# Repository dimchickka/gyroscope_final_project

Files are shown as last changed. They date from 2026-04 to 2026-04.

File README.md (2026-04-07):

Gyroscope Data Logger (STM32F103C8T6)
Overview
This project is an autonomous data logging device built around the STM32F103C8T6 (Blue Pill) microcontroller. It reads real-time data from a gyroscope sensor and saves the logs directly onto an SD card. The device is designed for portability, powered by a LiPo battery featuring convenient USB charging.

Photo Gallery
<div align="center">
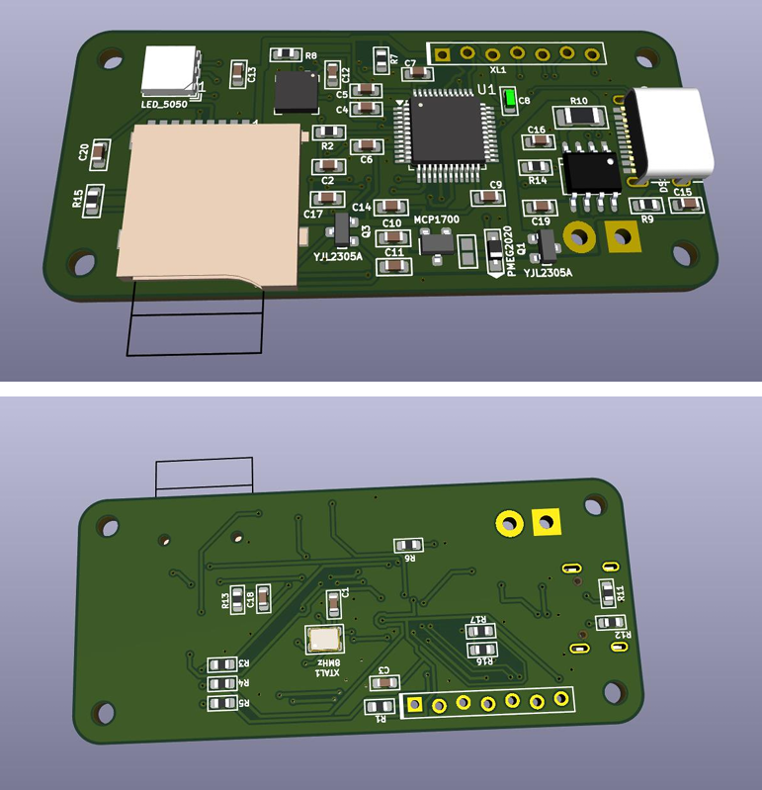
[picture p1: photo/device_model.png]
Model in KiCAD View

</div>

<div align="center">
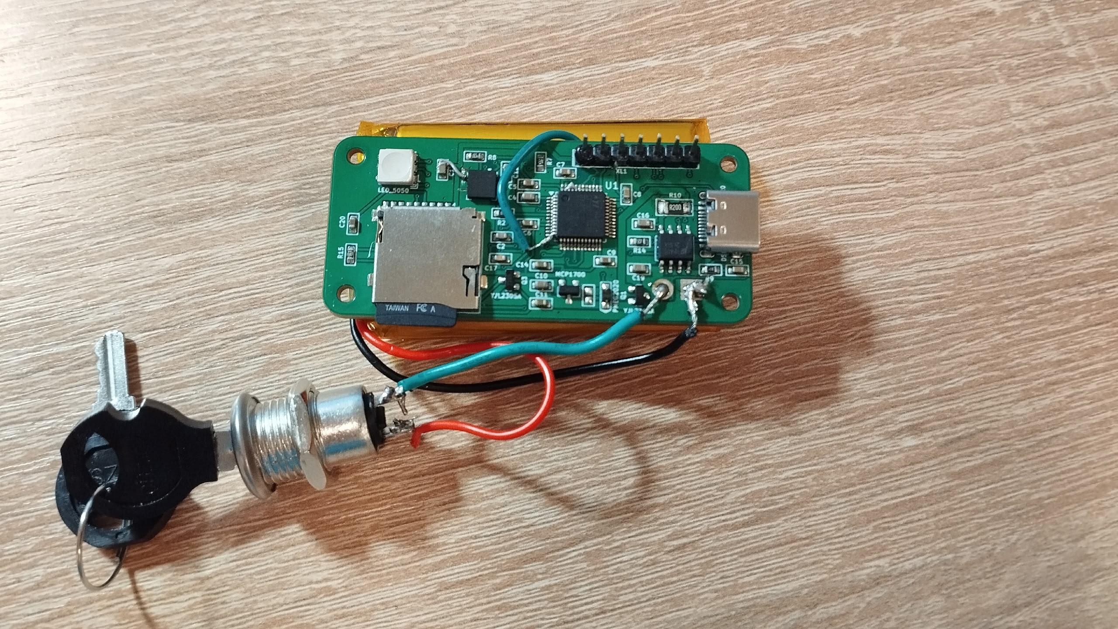
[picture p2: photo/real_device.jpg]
Assembled Device View

<p><em>The fully assembled Gyroscope Data Logger.</em></p>
</div>

🚀 Key Features
Microcontroller: STM32F103C8T6 (Cortex-M3).

Sensor: High-precision Gyroscope (interfaced via I2C).

Data Storage: Reliable data logging to a MicroSD card

Power System: Portable LiPo battery operation with an integrated USB charging circuit.

Communication Interfaces:

SPI: Used for high-speed communication with the SD card module.

I2C: Used for retrieving sensor data from the gyroscope.

UART: Available for debugging purposes.

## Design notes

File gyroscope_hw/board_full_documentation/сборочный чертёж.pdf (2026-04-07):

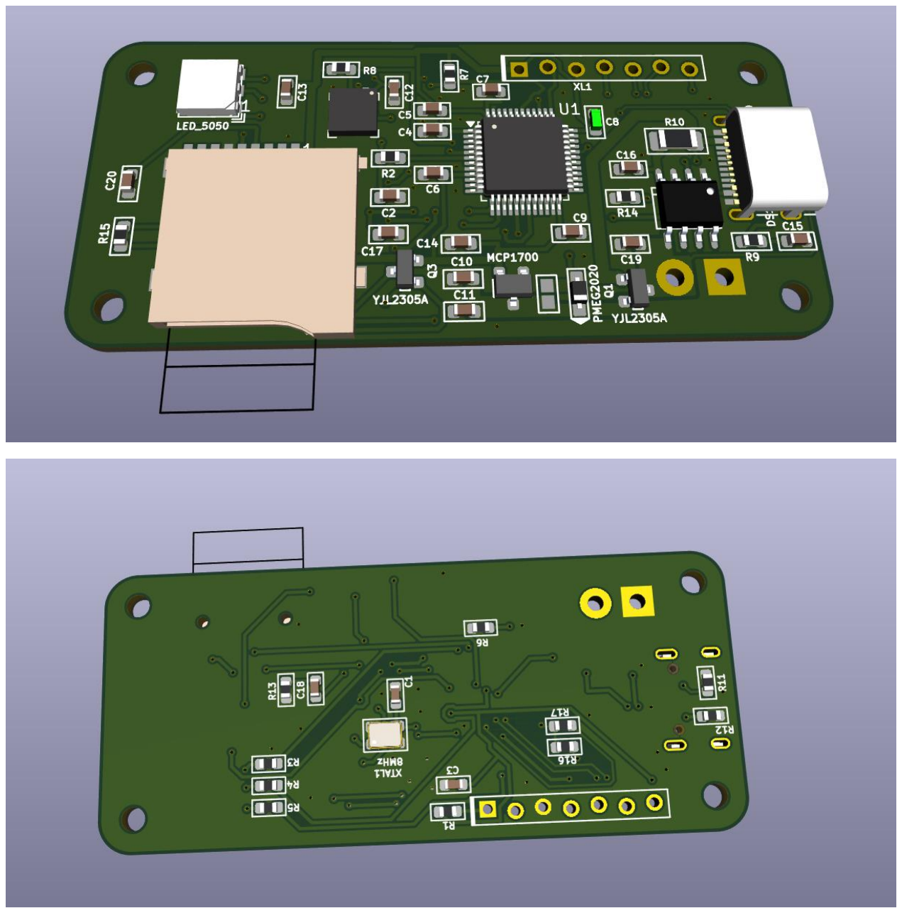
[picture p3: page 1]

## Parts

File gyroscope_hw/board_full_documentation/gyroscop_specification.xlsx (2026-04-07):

Reference,"Qty","Value","DNP","Exclude from BOM","Exclude from Board","Footprint","Datasheet"
C1,C2,"2","18pF","","","","Capacitors:CAP_0603_Silks",""
C3,C5,C6,C7,C8,C9,C12,C20,"8","0.1u","","","","Capacitors:CAP_0603_Silks",""
C4,C10,C13,C16,C19,"5","10u","","","","Capacitors:CAP_0603_Silks",""
C11,C14,"2","1u","","","","Capacitors:CAP_0603_Silks",""
C15,"1","2u2","","","","Capacitors:CAP_0603_Silks",""
C17,"1","10n","","","","Capacitors:CAP_0603_Silks",""
C18,"1","470n","","","","Capacitors:CAP_0603_Silks",""
D1,"1","PMEG2020","","","","Diodes:SOD323",""
D2,"1","L3G4200D","","","","Package_LGA:LGA-16_4x4mm_P0.65mm_LayoutBorder4x4y",""
DA1,"1","MCP1700","","","","SOT:SOT23-3A","D:/Datasheets/Power/Linear regulators/MC7800-D 30V 1A out5V.pdf"
DA2,"1","TP4056","","","","SO_DIL_TSSOP:SO8_150MIL",""
F1,"1","Fuse0R","DNP","���������������� ���� �������������� ������������������","","Resistors:RES_0603_FUSE",""
H1,H2,H3,H4,"4","MountingHole","DNP","���������������� ���� �������������� ������������������","","MountingHole:MountingHole_2.2mm_M2","~"
Q1,Q3,"2","YJL2305A","","","","SOT:SOT23-3",""
Q2,"1","LED_5050","","","","LEDs:LED_5050",""
R1,R6,R13,"3","10k","","","","Resistors:RES_0603_Silks",""
R2,R3,R4,R5,"4","1k","","","","Resistors:RES_0603_Silks",""
R7,R8,"2","4k7","","","","Resistors:RES_0603_Silks",""
R9,"1","2R0","","","","Resistors:RES_0603_Silks",""
R10,"1","0R2","","","","Resistors:RES_1206",""
R11,R12,"2","5k1","","","","Resistors:RES_0603_Silks",""
R14,"1","1.2k","","","","Resistors:RES_0603_Silks",""
R15,"1","56k","","","","Resistors:RES_0603_Silks",""
R16,R17,"2","100k","","","","Resistors:RES_0603_Silks",""
U1,"1","STM32F103C8Tx","","","","Package_QFP:LQFP-48_7x7mm_P0.5mm","https://www.st.com/resource/en/datasheet/stm32f103c8.pdf"
XL1,"1","SOCKET_7","DNP","���������������� ���� �������������� ������������������","","Connectors:PLS-7_LOCK",""
XL2,"1","CONN_1","","","","PCB:Round_1MM5",""
XL3,"1","CONN_1","","","","PCB:Square_1MM5",""
XL4,"1","DS1144-18-16FS8BNR0","","","","Connectors:USBC_DS1144-18",""
XL5,"1","CONN_MICROSD","","","","Installation:MICROSD_EJECTOR_TFWF1",""
XTAL1,"1","8MHz","","","","Quartz:03225C4",""

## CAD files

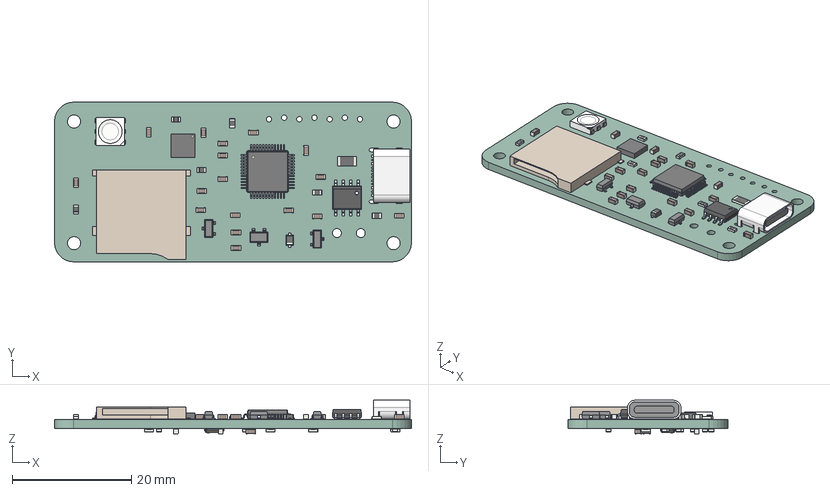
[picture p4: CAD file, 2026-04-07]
gyroscope_hw/gyroscope/gyroscope.step
59.8 x 26.8 x 5.62 mm
C_0603 x 20
Conn_MicroSD_TFWF1
SOT-23 x 3
SOD323F
R_0603 x 16
SO8
LED_5050
R_1206
USBC_10PF-074
LQFP-48_7x7mm_P0.5mm
LGA-16_4x4mm_P0.65mm_LayoutBorder4x4y
gyroscope_PCB

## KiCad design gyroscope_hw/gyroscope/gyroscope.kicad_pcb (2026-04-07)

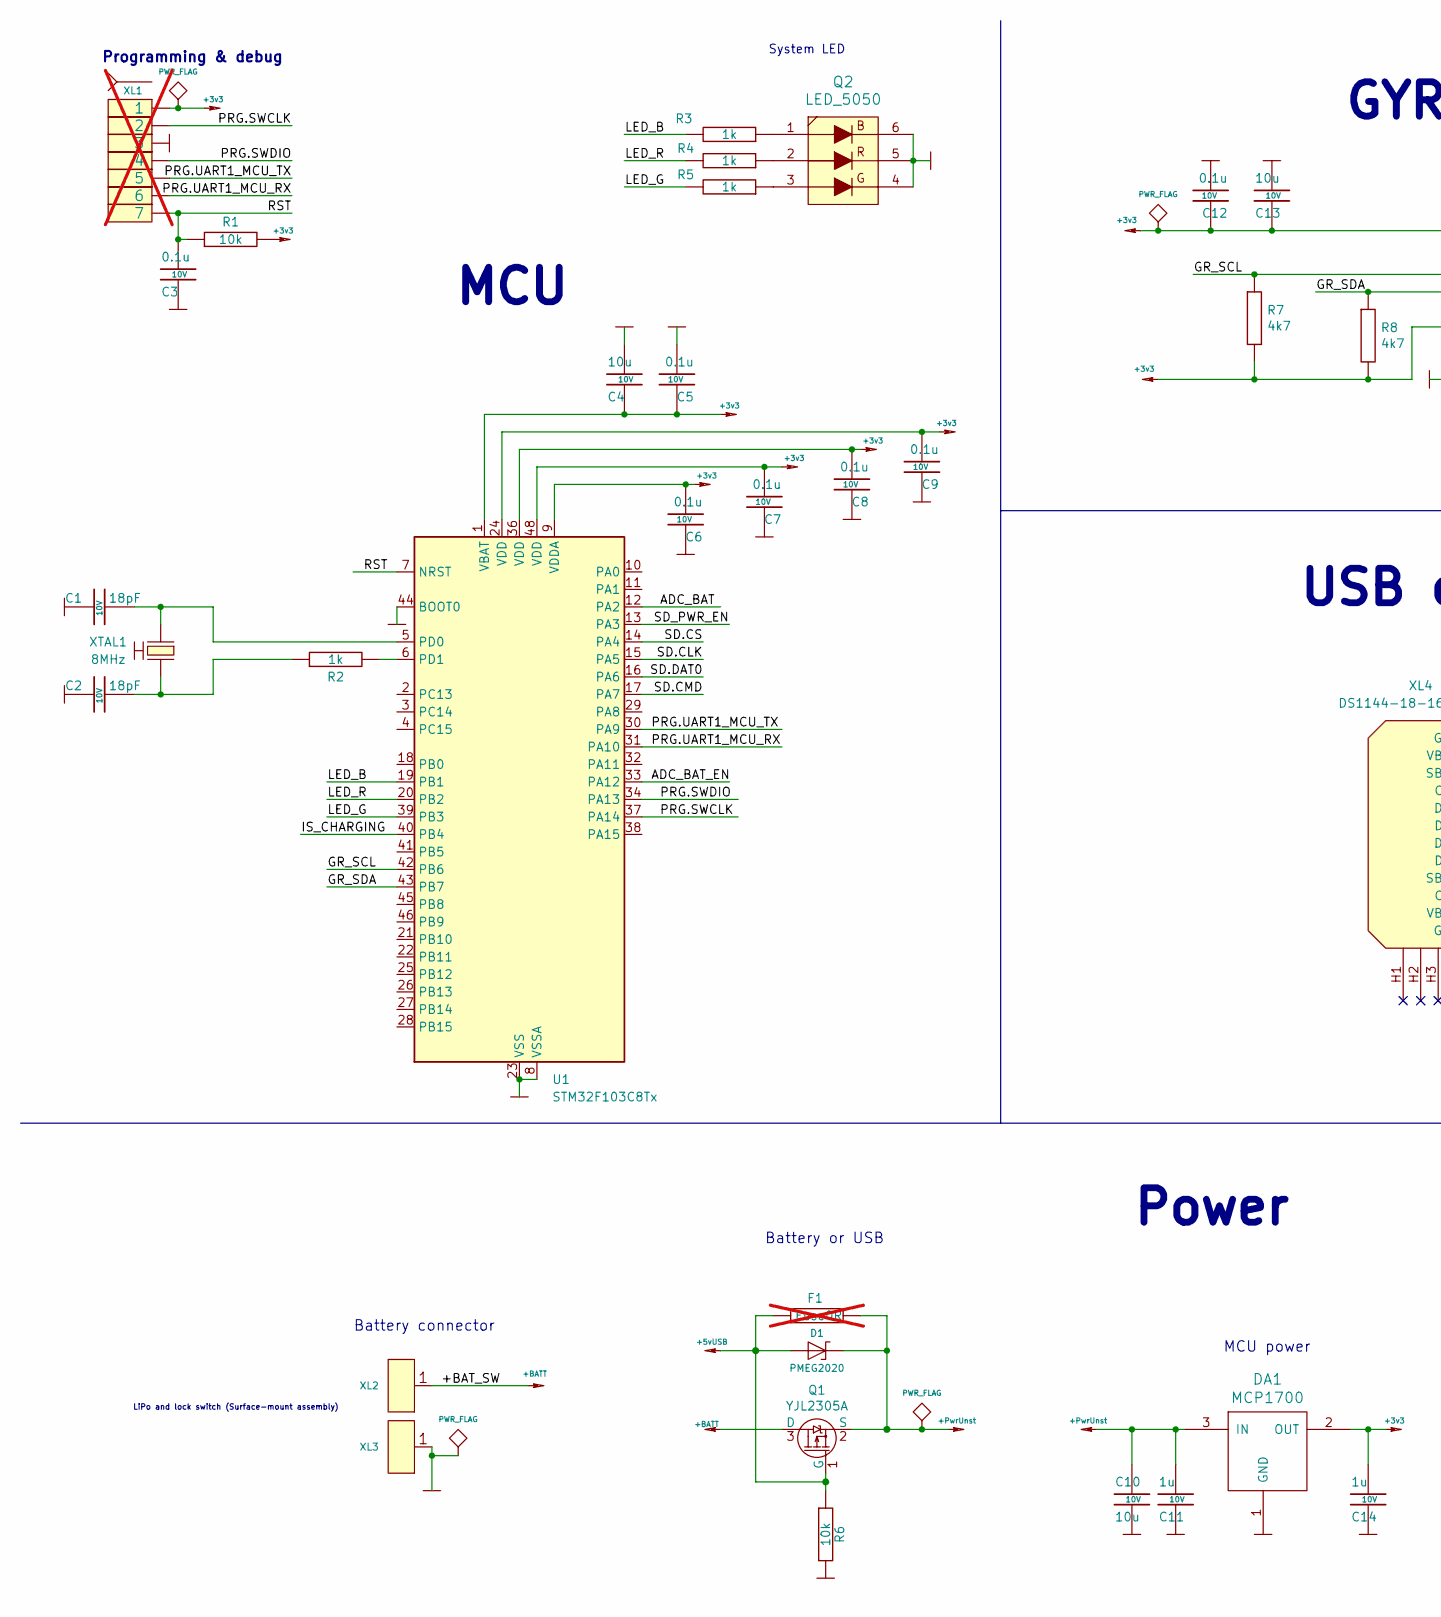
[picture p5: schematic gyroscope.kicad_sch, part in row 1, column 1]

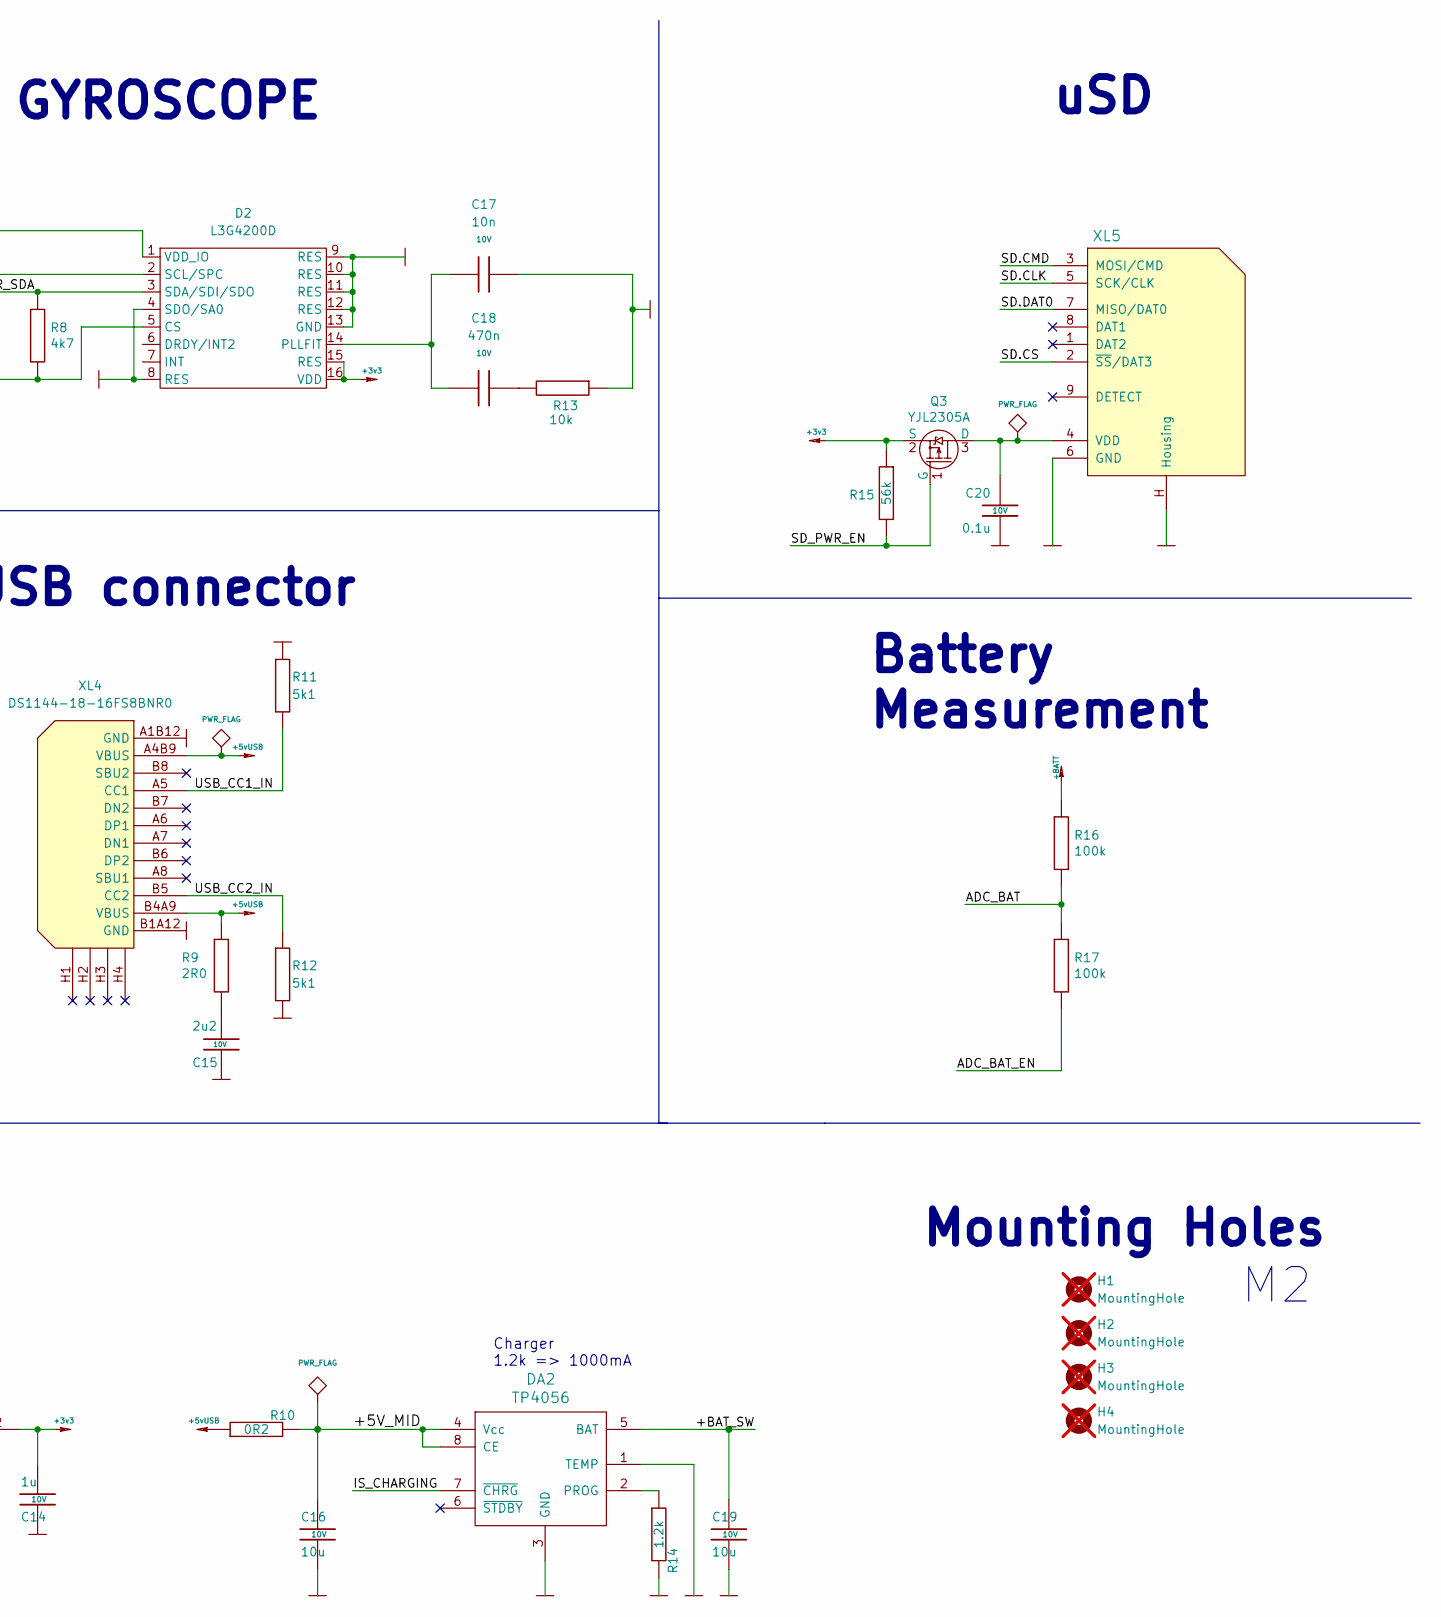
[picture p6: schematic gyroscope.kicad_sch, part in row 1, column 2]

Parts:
C1, C2: 18pF; CAP_0603_Silks; Tolerance 20%; Voltage 10V
C3, C5, C6, C7, C8, C9, C12: 0.1u; CAP_0603_Silks; Tolerance 20%; Voltage 10V
C4, C10, C13, C16, C19: 10u; CAP_0603_Silks; Tolerance 20%; Voltage 10V
C11, C14: 1u; CAP_0603_Silks; Tolerance 20%; Voltage 10V
C15: 2u2; CAP_0603_Silks; Tolerance 20%; Voltage 10V
C17: 10n; CAP_0603_Silks; Tolerance 20%; Voltage 10V
C18: 470n; CAP_0603_Silks; Tolerance 20%; Voltage 10V
C20: 0.1u; CAP_0603_Silks; Voltage 10V; Tolerance 20%
D1: PMEG2020; SOD323
D2: L3G4200D; LGA-16_4x4mm_P0.65mm_LayoutBorder4x4y
DA1: MCP1700; SOT23-3A
DA2: TP4056; SO8_150MIL
F1: Fuse0R; RES_0603_FUSE; not fitted
H1, H2, H3, H4: MountingHole; MountingHole_2.2mm_M2; not fitted
Q1, Q3: YJL2305A; SOT23-3
Q2: LED_5050
R1, R6, R13: 10k; RES_0603_Silks; Tolerance 1%
R2, R3, R4, R5: 1k; RES_0603_Silks; Tolerance 1%
R7, R8: 4k7; RES_0603_Silks; Tolerance 1%
R9: 2R0; RES_0603_Silks; Tolerance 1%
R10: 0R2; RES_1206; Tolerance 1%
R11, R12: 5k1; RES_0603_Silks; Tolerance 1%
R14: 1.2k; RES_0603_Silks; Tolerance 1%
R15: 56k; RES_0603_Silks; Tolerance 1%
R16, R17: 100k; RES_0603_Silks; Tolerance 1%
U1: STM32F103C8Tx; LQFP-48_7x7mm_P0.5mm
XL1: SOCKET_7; PLS-7_LOCK; not fitted
XL2: CONN_1; Round_1MM5
XL3: CONN_1; Square_1MM5
XL4: DS1144-18-16FS8BNR0; USBC_DS1144-18
XL5: CONN_MICROSD; MICROSD_EJECTOR_TFWF1
XTAL1: 8MHz; 03225C4

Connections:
+3v3: C4.2, C5.2, C6.1, C7.1, C8.1, C9.1, C12.2, C13.2, C14.1, D2.1 (VDD_IO), D2.5 (CS), D2.15 (RES), D2.16 (VDD), DA1.2 (OUT), Q3.2 (S), R1.2, R7.2, R8.2, R15.1, U1.1 (VBAT), U1.9 (VDDA), U1.24 (VDD), U1.36 (VDD), U1.48 (VDD), XL1.1
+5vUSB: D1.A, F1.1, Q1.1 (G), R6.1, R9.1, R10.1, XL4.A4B9 (VBUS), XL4.B4A9 (VBUS)
+BATT: C19.2, DA2.5 (BAT), Q1.3 (D), R16.1, XL2.1
+PwrUnst: C10.2, C11.1, D1.C, DA1.3 (IN), F1.2, Q1.2 (S)
/+5V_MID: C16.2, DA2.4 (Vcc), DA2.8 (CE), R10.2
/ADC_BAT: R16.2, R17.1, U1.12 (PA2)
/ADC_BAT_EN: R17.2, U1.33 (PA12)
/GR_SCL: D2.2 (SCL/SPC), R7.1, U1.42 (PB6)
/GR_SDA: D2.3 (SDA/SDI/SDO), R8.1, U1.43 (PB7)
/IS_CHARGING: DA2.7 (~CHRG), U1.40 (PB4)
/LED_B: R3.2, U1.19 (PB1)
/LED_G: R5.2, U1.39 (PB3)
/LED_R: R4.2, U1.20 (PB2)
/PRG.SWCLK: U1.37 (PA14), XL1.2
/PRG.SWDIO: U1.34 (PA13), XL1.4
/PRG.UART1_MCU_RX: U1.31 (PA10), XL1.6
/PRG.UART1_MCU_TX: U1.30 (PA9), XL1.5
/RST: C3.1, R1.1, U1.7 (NRST), XL1.7
/SD.CLK: U1.15 (PA5), XL5.5 (SCK/CLK)
/SD.CMD: U1.17 (PA7), XL5.3 (MOSI/CMD)
/SD.CS: U1.14 (PA4), XL5.2 (~SS/DAT3)
/SD.DAT0: U1.16 (PA6), XL5.7 (MISO/DAT0)
/SD_PWR_EN: Q3.1 (G), R15.2, U1.13 (PA3)
/USB_CC1_IN: R11.2, XL4.A5 (CC1)
/USB_CC2_IN: R12.1, XL4.B5 (CC2)
GND: C1.2, C2.2, C3.2, C4.1, C5.1, C6.2, C7.2, C8.2, C9.2, C10.1, C11.2, C12.1, C13.1, C14.2, C15.2, C16.1, C17.2, C19.1, C20.2, D2.4 (SDO/SA0), D2.8 (RES), D2.9 (RES), D2.10 (RES), D2.11 (RES), D2.12 (RES), D2.13 (GND), DA1.1 (GND), DA2.1 (TEMP), DA2.3 (GND), Q2.4 (B), Q2.5 (G), Q2.6, R6.2, R11.1, R12.2, R13.1, R14.2, U1.8 (VSSA), U1.23 (VSS), U1.35 (VSS), U1.44 (BOOT0), U1.47 (VSS), XL1.3, XL3.1, XL4.A1B12 (GND), XL4.B1A12 (GND), XL5.6 (GND), XL5.H (Housing), XTAL1.H
unnamed: C2.1, R2.1, XTAL1.2
unnamed: C15.1, R9.2
unnamed: C18.2, R13.2
unnamed: C17.1, C18.1, D2.14 (PLLFIT)
unnamed: DA2.2 (PROG), R14.1
unnamed: Q2.1, R3.1
unnamed: Q2.2, R4.1
unnamed: Q2.3, R5.1
unnamed: C20.1, Q3.3 (D), XL5.4 (VDD)
unnamed: C1.1, U1.5 (PD0), XTAL1.1
unnamed: R2.2, U1.6 (PD1)

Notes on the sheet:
Charger 1.2k => 1000mA
Battery connector
MCU
MCU power
Power
USB connector
Battery Measurement
LiPo and lock switch (Surface-mount assembly)
Mounting Holes
GYROSCOPE
Battery or USB
Programming & debug
System LED
uSD

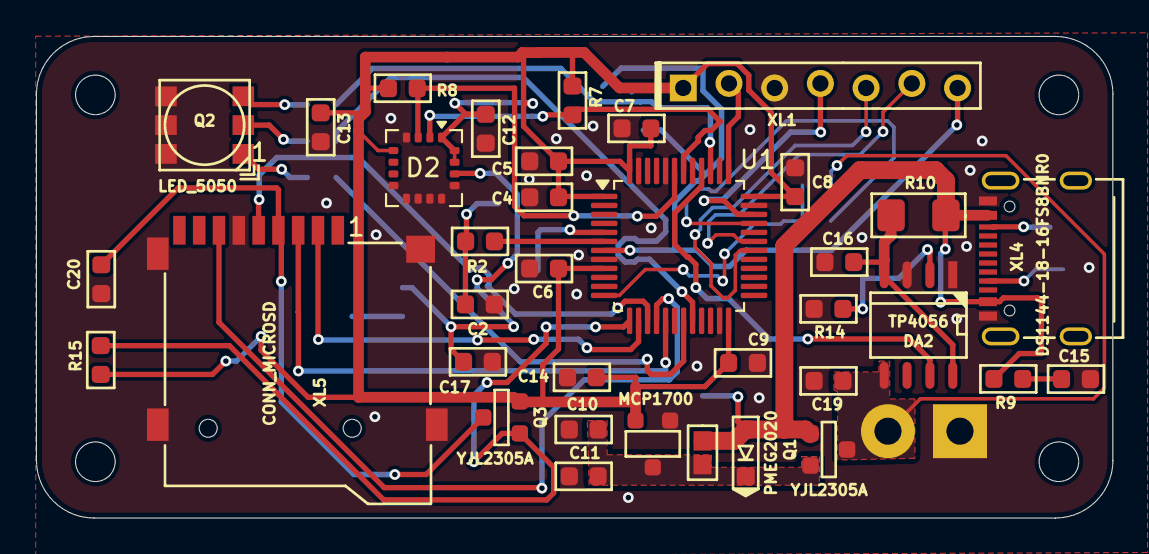
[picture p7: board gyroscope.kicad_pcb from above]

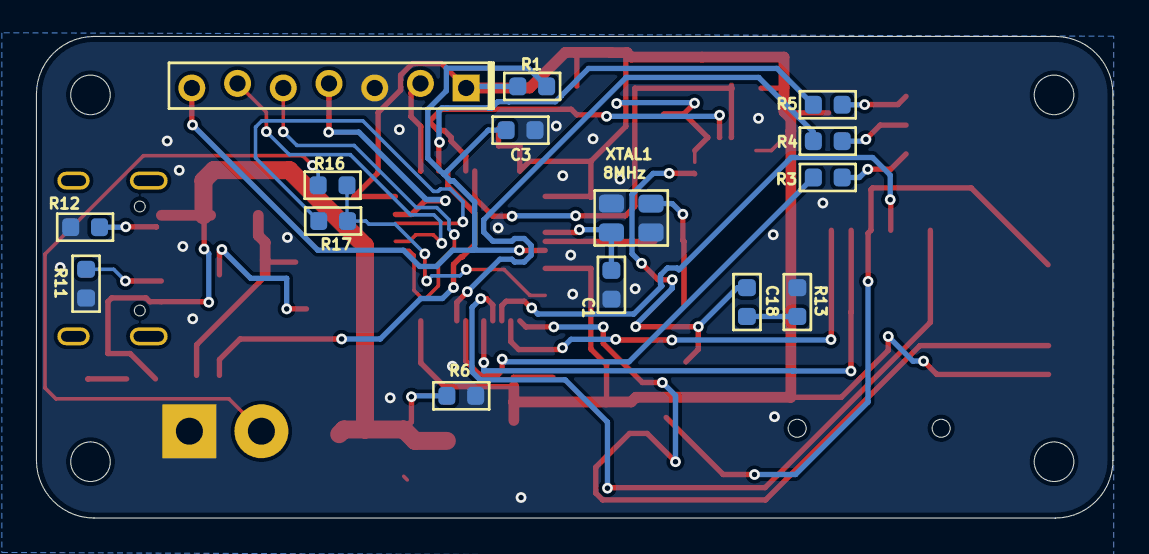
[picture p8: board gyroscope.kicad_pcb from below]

Board: 2 copper layers, 59.8 x 26.8 mm, 56 parts (16 on the bottom side), 37 nets.

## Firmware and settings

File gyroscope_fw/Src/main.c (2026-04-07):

#include "main.h"

char buffer[512]; //Буфер данных для записи/чтения
uint32_t numberOfPoints = 0;
volatile uint16_t Timer2=0; //Глобальная переменная для таймера-счётчика
volatile uint16_t counterToCheckBatteryCondition = 0;
bool isChargeOnBatteryEnough = true;
ADC_HandleTypeDef hadc1;
TIM_HandleTypeDef htim2;

int main(void){
    HAL_GPIO_WritePin(SD_PWR_EN_PORT, SD_PWR_EN_PIN, 0);
    MCU_Init();
    HAL_GPIO_WritePin(LED_GREEN_PORT, LED_GREEN_PIN, 1);
    HAL_Delay(1000);
    HAL_GPIO_WritePin(LED_GREEN_PORT, LED_GREEN_PIN, 0);
    HAL_GPIO_WritePin(LED_RED_PORT, LED_RED_PIN, 1);
    HAL_Delay(1000);
    HAL_GPIO_WritePin(LED_RED_PORT, LED_RED_PIN, 0);
    HAL_GPIO_WritePin(LED_BLUE_PORT, LED_BLUE_PIN, 1);
    HAL_Delay(1000);
    HAL_GPIO_WritePin(LED_BLUE_PORT, LED_BLUE_PIN, 0);
    GyroData_t gyroData = {0};
    if(isErrorFlag) HAL_GPIO_WritePin(LED_GREEN_PORT, LED_GREEN_PIN, 1);
    while (1){
       processAlgorithm(buffer, &gyroData);
     }
}

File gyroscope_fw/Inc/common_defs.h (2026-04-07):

#ifndef COMMON_DEFS_H
#define COMMON_DEFS_H

#include <stdint.h> 
#include <string.h> 
#include <stdbool.h>
#include <stdio.h>
#include <stdlib.h>
#include "stm32f1xx_hal.h"

//-----------------------//CONFIGURATION DATA//------------

extern uint32_t timeFromTheStartOfMCU;
extern uint32_t indexOfIteration;

//-----------------------//FLAGS//------------

extern bool isErrorFlag;
extern bool isFirstStep;
extern bool is_charging;
extern bool is_first_iteration;

extern bool isChargeOnBatteryEnough;
extern bool isBatteryConditionNeedsToBeChecked;
//-----------------------//RESULT OF OPERATIONS//------------

#define SUCCESS_EXECUTION 0
#define ERROR_EXECUTION 1

//-----------------------//ADDRESSES OF SD CARD//------------

#define CONFIG_SECTOR 0x1000U  //4096 сектор
#define START_SECTOR 0x1001U   //4097 сектор
//Считаем, что подключена SD карта размером 30Гб
//Считаем, что доступно 62 млн. секторов
#define END_SECTOR 0x03B1E6C0U
#define SECTOR_SIZE 512U

//-----------------------//GPIO PINS//------------
//*****LED for indication*****
#define LED_RED_PORT   GPIOB
#define LED_RED_PIN    GPIO_PIN_1

#define LED_GREEN_PORT    GPIOB
#define LED_GREEN_PIN     GPIO_PIN_2

#define LED_BLUE_PORT  GPIOB
#define LED_BLUE_PIN   GPIO_PIN_3

//*****System pins*****
#define SD_PWR_EN_PORT  GPIOA      
#define SD_PWR_EN_PIN   GPIO_PIN_3

#define ADC_BAT_EN_PORT GPIOA
#define ADC_BAT_EN_PIN  GPIO_PIN_12

#define ADC_BAT_IN_PORT  GPIOA
#define ADC_BAT_IN_PIN   GPIO_PIN_2

#define IS_CHARGING_PORT  GPIOB
#define IS_CHARGING_PIN   GPIO_PIN_4

//*****USART1*****
#define USART1_TX_PORT      GPIOA
#define USART1_TX_PIN       GPIO_PIN_9
#define USART1_RX_PORT      GPIOA
#define USART1_RX_PIN       GPIO_PIN_10

//*****I2C*****
#define I2C1_PORT    GPIOB
#define I2C1_SCL_PIN GPIO_PIN_6
#define I2C1_SDA_PIN GPIO_PIN_7

//*****SPI1*****
#define SPI1_PORT    GPIOA
#define SPI1_SCK_PIN GPIO_PIN_5
#define SPI1_MOSI_PIN GPIO_PIN_7
#define SPI1_MISO_PIN GPIO_PIN_6
#define SPI1_CS_PIN GPIO_PIN_4

//-----------------------//Gyroscope//------------

extern uint32_t STEP_TO_READ_MS;
#define I2C_TIMEOUT_MS 10  // мс
#define UART_TIMEOUT_MKS 10  // мкс
#define STEP_TO_READ_S 0.01f // с

typedef struct {
    int16_t x_prev, y_prev, z_prev;
    int16_t x_current, y_current, z_current;
    float ax, ay, az;   // угловое ускорение
} GyroData_t;


//-----------------------//ERROR HANDLER//------------

extern void Error_Handler(void);


#endif
